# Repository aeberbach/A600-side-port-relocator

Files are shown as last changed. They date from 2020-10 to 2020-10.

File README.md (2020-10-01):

# A600 right side port relocator

(what do you even name this thing?)

It's just a trio of connectors with a PCB between. The A600 has its ports for mouse and game controllers on the right. The joystick port is right up against a pice of plastic molding so you can't get anything but a slim plug in there. Wires connected to either port will tend to stick out to the right and get in the way of the mouse. It was a pretty horrible place to put these ports but maybe it was the cheapest.

The idea is that this device plugs into the side of the Amiga 600 and the two ports are relocated using a single stacked connector at the back of the machine. The mouse port is on the bottom and hopefully the mouse cord gets in the way less there. The joystick port is on top and is probably easier to reach, also joysticks with large plugs can be used. Either port can have wide (i.e. DIY) connectors plugged in.

A single-sided PCB is used to keep cost as low as possible and because it costs no extra to use thick fibreglass, it is thick to make it sturdy. The 3D printed cover is optional but recommended, it covers the electrical connections of the ports underneath the PCB just in case you decide to put your Amiga on a conductive surface. It looks nicer too.

Parts:
Stacked DE-9 male pair: https://www.digikey.com.au/product-detail/en/L17H2110130/L17H2110130-ND/
Single DE-9 female: https://www.digikey.com.au/product-detail/en/ID09S33E4GX00LF/609-5771-ND

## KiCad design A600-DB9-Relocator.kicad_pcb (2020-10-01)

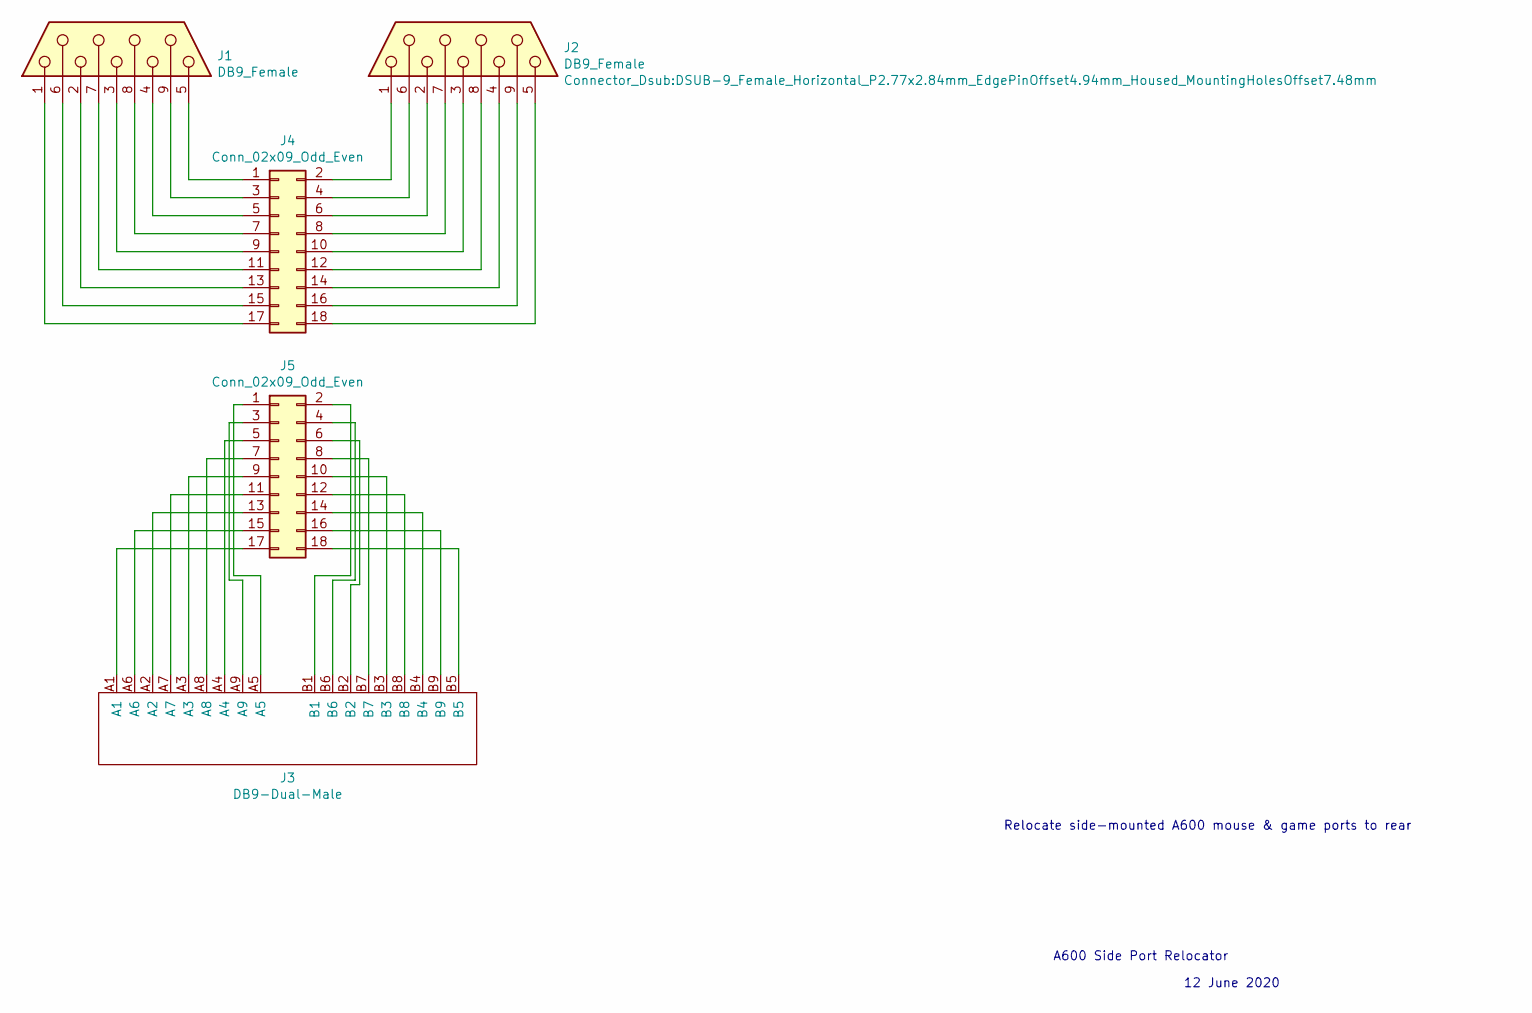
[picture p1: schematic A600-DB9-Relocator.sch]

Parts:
J1, J2: DB9_Female; DSUB-9_Female_Horizontal_P2.77x2.84mm_EdgePinOffset4.94mm_H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
J3: DB9-Dual-Male; CONN-DUAL-D-SUB-9POS-RA-SLDR
J4, J5: Conn_02x09_Odd_Even; PinHeader_2x09_P2.54mm_Vertical

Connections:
unnamed: J1.1, J4.17
unnamed: J1.2, J4.13
unnamed: J1.3, J4.9
unnamed: J1.4, J4.5
unnamed: J1.5, J4.1
unnamed: J1.6, J4.15
unnamed: J1.7, J4.11
unnamed: J1.8, J4.7
unnamed: J1.9, J4.3
unnamed: J2.1, J4.2
unnamed: J2.2, J4.6
unnamed: J2.3, J4.10
unnamed: J2.4, J4.14
unnamed: J2.5, J4.18
unnamed: J2.6, J4.4
unnamed: J2.7, J4.8
unnamed: J2.8, J4.12
unnamed: J2.9, J4.16
unnamed: J3.A1, J5.17
unnamed: J3.A2, J5.13
unnamed: J3.A3, J5.9
unnamed: J3.A4, J5.5
unnamed: J3.A5, J5.1
unnamed: J3.A6, J5.15
unnamed: J3.A7, J5.11
unnamed: J3.A8, J5.7
unnamed: J3.A9, J5.3
unnamed: J3.B1, J5.2
unnamed: J3.B2, J5.6
unnamed: J3.B3, J5.10
unnamed: J3.B4, J5.14
unnamed: J3.B5, J5.18
unnamed: J3.B6, J5.4
unnamed: J3.B7, J5.8
unnamed: J3.B8, J5.12
unnamed: J3.B9, J5.16

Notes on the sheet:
Relocate side-mounted A600 mouse & game ports to rear
A600 Side Port Relocator
12 June 2020

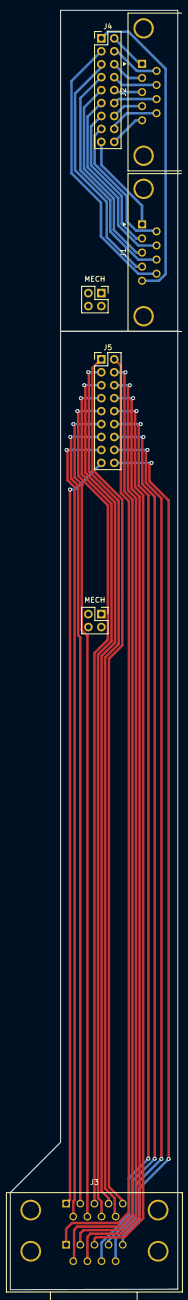
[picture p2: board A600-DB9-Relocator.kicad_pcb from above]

Board: 2 copper layers, 32.9 x 251.1 mm, 7 parts (0 on the bottom side), 36 nets.

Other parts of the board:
MECH: PinSocket_2x02_P2.54mm_Vertical
MECH#2: PinSocket_2x02_P2.54mm_Vertical

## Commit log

2020-06-12 Initial commit of project files
    [A600-DB9-Relocator.kicad_pcb, A600-DB9-Relocator.sch]
2020-09-30 PCB complete
    [A600-DB9-Relocator.kicad_pcb, A600-DB9-Relocator.sch]
2020-10-01 Corrected routing; title block
    [A600-DB9-Relocator.kicad_pcb, A600-DB9-Relocator.sch]
2020-10-01 Add digikey part numbers for the connectors

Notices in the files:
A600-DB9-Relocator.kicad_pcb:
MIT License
